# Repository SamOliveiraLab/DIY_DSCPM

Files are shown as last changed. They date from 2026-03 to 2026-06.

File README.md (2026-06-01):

# An Open-Source Platform Enabling Continuous, Low-Flow Control for Long-Term Operation in Biotechnology Systems

A GUI software and hardware platform for imposing flow rates and behaviors in a DIY pump mechanism. Supports multiple pump connections, four flow behavior modes, scheduled command sequences, and experiment file generation.

## Demo Videos

Hardware Demo (https://www.youtube.com/watch?v=BdsErtyMBxU)
GUI Demo (https://www.youtube.com/watch?v=6b1y6uDTwsg)

Full DSCPM Edge Detection playlist: <https://www.youtube.com/playlist?list=PL5P5w8v6POUNH2w5X_0y1NKzEqolb6u0d>

---

## Table of Contents

1. [Requirements](#requirements)
2. [Project Structure](#project-structure)
3. [Setup](#setup)
4. [Running the Application](#running-the-application)
5. [GUI Overview](#gui-overview)
6. [Connecting Pumps](#connecting-pumps)
7. [Pump Controls](#pump-controls)
8. [Flow Behaviors](#flow-behaviors)
9. [Pause / Resume / Restart](#pause--resume--restart)
10. [Text File Scheduling](#text-file-scheduling)
11. [Create Experiment Dialog](#create-experiment-dialog)
12. [Text File Format](#text-file-format)
13. [Arduino Command Protocol](#arduino-command-protocol)
14. [Troubleshooting](#troubleshooting)

---

## Requirements

- Python 3.8+
- PyQt5
- pyserial
- Arduino board with the DSCPM firmware loaded 

Install Python dependencies (pick one):

**uv (recommended):**

```bash
uv sync
```

**pip:**

```bash
pip install PyQt5 pyserial
```

## Project Structure

```
DSCPM_v2/
├── Arduino_code/
│   └── pump_JS_07222025.ino    # Arduino firmware for pump control
├── Python code/
│   ├── GUI.py                  # Entry point - launches the application
│   ├── pump_app.py             # Main window, all GUI logic and widgets
│   ├── arduino_cmds.py         # Serial communication wrapper
│   ├── autoport.py             # USB port auto-detection and connection
│   └── pump_render.png         # Pump image displayed in the GUI
└── README.md
```

## Setup

1. **Flash the Arduino**: Open `Arduino_code` in the Arduino IDE and upload it to your board. The firmware uses pins 9 and 11 for servos and pins 5, 6, 10 for solenoid valves. Baud rate is 9600.

2. **Connect hardware**: Plug the Arduino into your computer via USB. Note the serial number or device path if you plan to use manual connection.

3. **Install dependencies**: Run `uv sync` (or `pip install PyQt5 pyserial`).

## Running the Application

**With uv (from repo root):**

```bash
uv run python run_gui.py
```

**Classic (from `Python code`):**

```bash
cd "Python code"
python GUI.py
```

The Pump GUI window will open.

---

## GUI Overview

The interface is organized into rows from top to bottom:

| Row | Section | Purpose |
|-----|---|---|
| 0 | Pump Image | Visual reference of the pump hardware |
| 1 | Multi Pump Connect | Connect multiple pumps by entering serial numbers |
| 2 | Connect / Serial | Auto-connect or manually enter a serial number / device path |
| 3 | Flowrate Quick Adjust | Type a number (0–40) to change flow rate on the fly |
| 4 | On/Off + Direction | Turn the pump on/off and toggle flow direction |
| 5 | Flow Behavior | Select a flow mode, enter parameters, and apply |
| 6 | Pause / Resume / Restart | Control scheduled command execution |
| 7 | File Buttons | Create experiment, upload/change/run/exit text files |
| 8 | File Labels | Shows the currently selected file name |
| 9 | File Contents Display | Human-readable preview of the loaded command file |

---

## Connecting Pumps

### Auto Connect

Click **Auto Connect**. The software scans USB ports and connects to the first likely Arduino device. The button turns green on success.

### Manual Connect

Type a USB serial number (e.g. `054433A493735191B7D8`) or a device path (e.g. `/dev/cu.usbmodem1101`) into the serial input field and press Enter.

### Multiple Pumps

1. Enter the number of pumps (1–10) in the "Connect multiple pumps" field and press Enter.
2. A popup window appears - enter the serial number for each pump.
3. Click **Collect Serial #s**. The software connects to each Arduino and adds them to the pump dropdown.
4. Use the dropdown to switch between connected pumps.

---

## Pump Controls

### On/Off

- Click **Pump: OFF** to turn the pump on. Sends `123` to the Arduino.
- Click **Pump: ON** to turn it off. Sends `0` to the Arduino.
- The button changes color: green = on, red = off.

### Direction

- Click the **Direction** button to toggle between forward (`-->`) and backward (`<--`). Sends `321` to the Arduino.
- Direction only toggles when the pump is on.

### Quick Flowrate Adjust

Type an integer in the flowrate field and press Enter. This sends the number directly to the Arduino, which recalculates the servo delay for that flow rate in uL/min.

---

## Flow Behaviors

The **Flow Behavior** section provides four modes. Select a mode from the dropdown, fill in the visible parameters, then click **Apply Flow** to send the command.

### Constant

Steady flow in one direction.

| Parameter | Description |
|---|---|
| Flow Rate (uL/min) |  |

Command sent: `FLOWA,{rate}`

### Pulse

Intermittent on/off bursts.

| Parameter | Description |
|---|---|
| Flow Rate (uL/min) |  |
| Duty Cycle (0–1) | Fraction of each cycle the pump is active |
| Pulse Freq (Hz) | How many cycles per second |

Command sent: `FLOWB,{rate},{duty},{freq}`

### Oscillation

Back-and-forth flow.

| Parameter | Description |
|---|---|
| Flow Rate (uL/min) |  |
| Osc Freq (Hz) | Oscillation frequency |
| Osc Amplitude | Amplitude of the oscillation |

Command sent: `FLOWC,{rate},{freq},{amplitude}`

### Pulse of Oscillation

Pulsed bursts of oscillatory flow - combines both behaviors.

| Parameter | Description |
|---|---|
| Flow Rate (uL/min) |  |
| Pulse Freq (Hz) | Frequency of the pulse envelope |
| Duty Cycle (0–1) | Fraction of each pulse cycle that is active |
| Osc Amplitude | Amplitude of the oscillation within each pulse |
| Osc Freq (Hz) | Frequency of the oscillation within each pulse |

Command sent: `FLOWD,{rate},{pulse_freq},{duty},{osc_amplitude},{osc_freq}`

> **Note**: The Arduino firmware must be updated to parse and execute these `FLOW` commands. The current firmware only handles constant flow via numeric flow rate values.

---

## Pause / Resume / Restart

These buttons control scheduled command execution (from text files or generated experiments):

| Button | Action |
|---|---|
| **Pause** | Sends `0` to stop the pump. Freezes the command scheduler. All remaining command times are shifted forward so relative timing is preserved on resume. |
| **Resume** | Sends `123` to restart the pump. Unfreezes the scheduler and continues from where it left off. |
| **Restart Cycle** | Stops the current execution entirely, recalculates all command times from the original delays, and starts the full sequence over from the beginning. |

---

## Text File Scheduling

You can run pre-written command sequences from `.txt` files.

### Upload a File

Click **Upload .txt file**, browse to your file, and select it. The file name appears in the label and its contents are displayed in the preview area.

### Run a File

Click **Run .txt file**. The software parses the file, matches serial numbers to connected boards, and begins executing commands on a background thread at the scheduled times.

- If a worker is already running, new commands are merged into the existing schedule.
- If a serial number in the file doesn't match any connected board but only one board is connected, it falls back to that board.

### Change File

Click **Change current file** to cycle through previously uploaded files.

### Exit / Stop

Click **Exit current file** to kill the running scheduler, stop the pump, and clear all scheduled commands.

---

## Create Experiment Dialog

Click the purple **Create Experiment** button to open a dialog for building command sequences visually.

### Steps

1. **Select a pump** from the dropdown (uses connected pump names).
2. **Enter the time** in seconds from the start of the experiment.
3. **Choose a behavior**: Turn On, Turn Off, Change Direction, Constant, Pulse, Oscillation, or Pulse of Oscillation.
4. **Fill in the parameters** that appear for the selected behavior.
5. Click **Add Step**. The step appears in the table below.
6. Repeat for all steps in your experiment.

### Managing Steps

- Select a row in the table and click **Remove Selected** to delete it.
- Steps are sorted by time when the file is generated.

### Generating the File

Click **Generate & Save File**. A save dialog appears - choose a location and filename. The software:

1. Writes the `.txt` file to disk in the standard command format.
2. Loads it as the current file in the main GUI.
3. Displays the parsed commands in the file contents preview.

You can then click **Run .txt file** to execute the experiment immediately.

---

## Text File Format

Command files use this format, with entries separated by `%%%%%%%%%`:

```
SERIAL*********COMMAND#########DELAY%%%%%%%%%SERIAL*********COMMAND#########DELAY
```

| Field | Description |
|---|---|
| `SERIAL` | The Arduino's USB serial number (e.g. `054433A493735191B7D8`) |
| `COMMAND` | Any valid command string (see table below) |
| `DELAY` | Time in seconds from the start of execution |

### Example File

```
054433A493735191B7D8*********123#########0%%%%%%%%%054433A493735191B7D8*********FLOWA,10.0#########2%%%%%%%%%054433A493735191B7D8*********FLOWB,15.0,0.5,2.0#########30%%%%%%%%%054433A493735191B7D8*********0#########60
```

This sequence:
1. At 0s - Turn pump on
2. At 2s - Constant flow at 10 uL/min
3. At 30s - Switch to pulse mode (15 uL/min, 50% duty, 2 Hz)
4. At 60s - Turn pump off

---

## Arduino Command Protocol

Communication runs at **9600 baud**. The Arduino sends `READY` on startup; Python waits for this before proceeding.

### Commands (Python to Arduino)

| Command | Action |
|---|---|
| `0` | Turn pump off. Saves position to EEPROM. |
| `123` | Turn pump on. |
| `321` | Toggle flow direction. |
| `456` | Request status log (position, direction, valve state). |
| Any float (e.g. `10.5`) | Set flow rate in uL/min. Recalculates servo delay. |
| `FLOWA,{rate}` | Constant flow mode (firmware update required). |
| `FLOWB,{rate},{duty},{freq}` | Pulse mode (firmware update required). |
| `FLOWC,{rate},{freq},{amp}` | Oscillation mode (firmware update required). |
| `FLOWD,{rate},{pfreq},{duty},{oamp},{ofreq}` | Pulse of oscillation mode (firmware update required). |

### Responses (Arduino to Python)

| Response | When |
|---|---|
| `READY` | On startup, signals handshake complete |
| `System OFF. Position saved.` | After command `0` |
| `Pumps ON` | After command `123` |
| `Direction switched.` | After command `321` |
| `LOG: Position: X, FWD: Y...` | After command `456` |
| `Flow rate changed to X uL/min` | After a numeric flow rate command |

---

## Troubleshooting

**App won't start / ModuleNotFoundError**
- Make sure you've installed dependencies: `pip install PyQt5 pyserial`
- Run from inside the `Python code/` directory so relative imports work.

**"No device found" on connect**
- Check that the Arduino is plugged in via USB.
- On macOS, verify the device appears under `/dev/cu.*` (run `ls /dev/cu.*` in terminal).
- Try entering the device path manually (e.g. `/dev/cu.usbmodem1101`).

**Connect button turns red**
- The auto-detection couldn't find a matching device. Try manual serial entry or check USB connection.

**Pump doesn't respond to FLOW commands**
- The Arduino firmware (`pump_JS_07222025.ino`) does not yet handle `FLOWA`/`FLOWB`/`FLOWC`/`FLOWD` commands. Numeric flow rate changes and on/off/direction work. The firmware needs to be updated to parse the new comma-separated flow commands.

**Pause/Resume not working**
- These buttons only work when a text file schedule is running. For manual control, use the On/Off button directly.

**File displays "no valid commands found"**
- Check that the file uses the correct format: `SERIAL*********COMMAND#########DELAY` with `%%%%%%%%%` separators.

**Multiple pumps - wrong pump receives commands**
- Use the pump dropdown to select which pump you're controlling manually.
- In text files, make sure each command line uses the correct serial number for the target pump.

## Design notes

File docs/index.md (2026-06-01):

---
layout: default
---

This platform provides open-source software and hardware for imposing programmable flow rates and behaviors using a DIY syringe pump. It includes a desktop GUI for real-time pump control, Arduino firmware for motor and valve actuation, and four configurable flow modes - Constant, Pulse, Oscillation, and Pulse of Oscillation. Users can build and run scheduled experiments from the GUI and export them as text-based command files.

<p align="center">
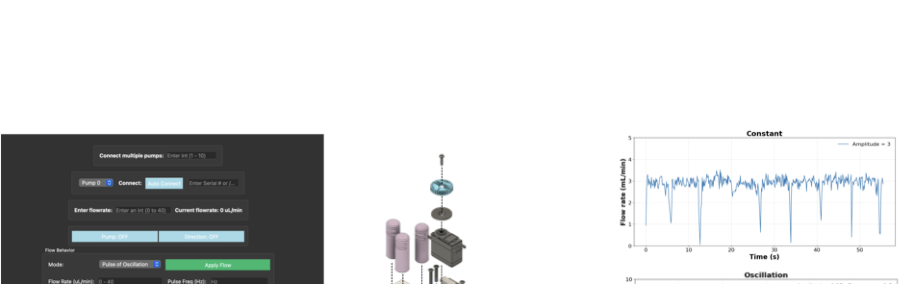
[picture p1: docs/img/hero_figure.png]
Platform Overview - GUI, Pump Hardware, Flow Behaviors
  
</p>

[View on GitHub](https://github.com/SamOliveiraLab/DIY_DSCPM){: .btn }

---

## Demos

<table align="center">
  <tr>
    <td align="center">
      <iframe width="420" height="236" src="https://www.youtube.com/embed/BdsErtyMBxU" frameborder="0" allowfullscreen></iframe>
      <br><b>Hardware Demo</b>
    </td>
    <td align="center">
      <iframe width="420" height="236" src="https://www.youtube.com/embed/6b1y6uDTwsg" frameborder="0" allowfullscreen></iframe>
      <br><b>GUI Demo</b>
    </td>
    <td align="center">
      <iframe width="420" height="236" src="https://www.youtube.com/embed/videoseries?list=PL5P5w8v6POUNH2w5X_0y1NKzEqolb6u0d" frameborder="0" allowfullscreen></iframe>
      <br><b><a href="https://www.youtube.com/playlist?list=PL5P5w8v6POUNH2w5X_0y1NKzEqolb6u0d" style="color: inherit; text-decoration: none;">Edge Detection Playlist</a></b>
    </td>
  </tr>
</table>

---

## Quick Links

| Page | Description |
|---|---|
| [Setup & Installation](setup.html) | Requirements, dependencies, and how to run |
| [GUI User Guide](guide.html) | Full walkthrough of every feature |
| [Flow Behaviors](flow.html) | Constant, Pulse, Oscillation, and Pulse of Oscillation modes |
| [Experiment Builder](experiment.html) | Creating and running scheduled experiments |
| [Arduino Protocol](protocol.html) | Command format between Python and the microcontroller |
| [Troubleshooting](troubleshooting.html) | Common issues and fixes |

---

## Project Structure

```
DIY_DSCPM/
├── Arduino_code/
│   └── pump_JS_07222025.ino    # Arduino firmware
├── Python code/
│   ├── GUI.py                  # Entry point
│   ├── pump_app.py             # Main window and logic
│   ├── arduino_cmds.py         # Serial communication
│   ├── autoport.py             # USB auto-detection
│   └── pump_render.png         # Pump image
├── dist/
│   ├── PumpGUI.app             # Standalone macOS app
│   └── PumpGUI                 # Standalone CLI executable
└── README.md
```

---

*Developed at the [Oliveira Lab](https://github.com/SamOliveiraLab), North Carolina A&T State University.*

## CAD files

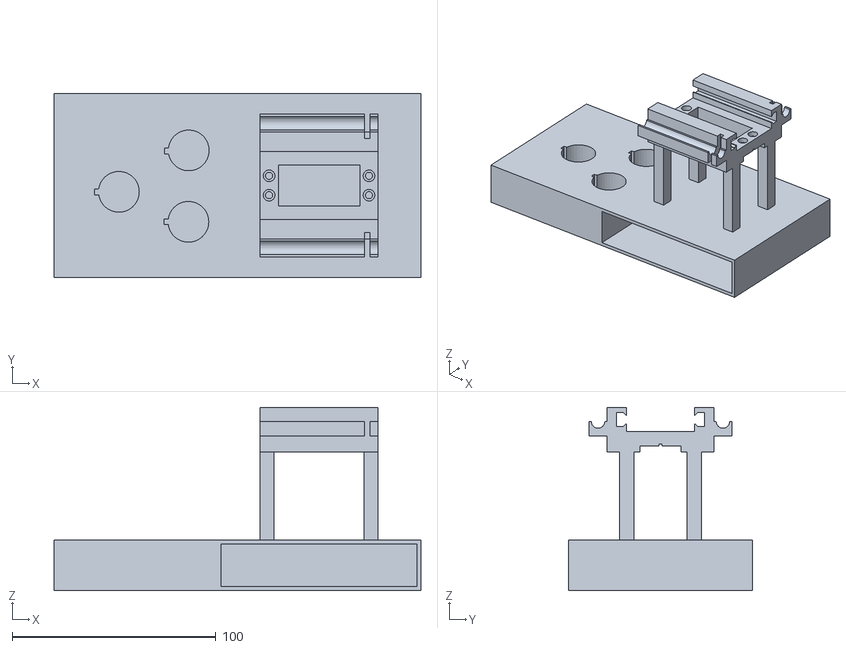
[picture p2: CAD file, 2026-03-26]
Design Files/DIY PUMP – MainBase.stl
180.0 x 90.2 x 90.0

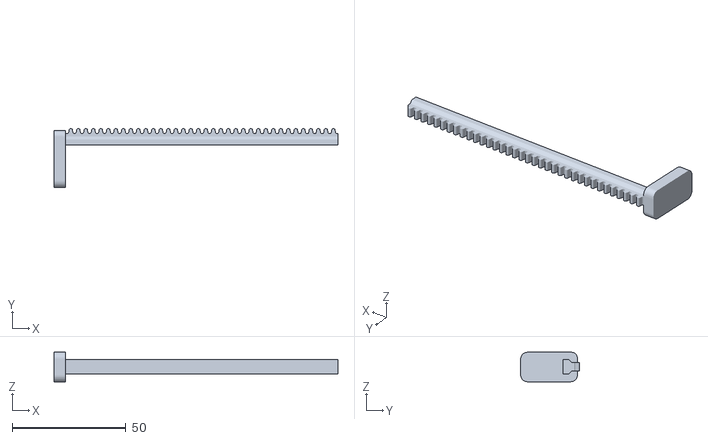
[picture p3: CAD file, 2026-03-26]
Design Files/Pusher_125mm_Long.stl
125.0 x 25.8 x 13.0

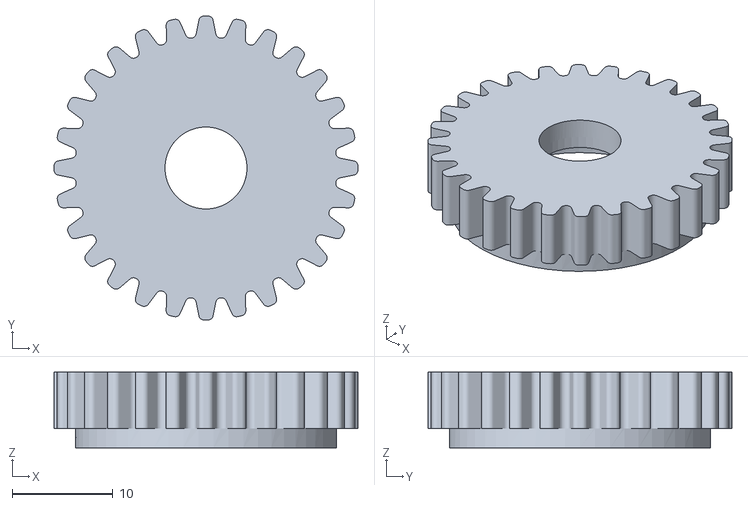
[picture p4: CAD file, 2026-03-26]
Design Files/Pinion_Gear_with_Hole.stl
30.2 x 30.2 x 7.51

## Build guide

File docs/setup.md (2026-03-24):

---
layout: default
title: Setup & Installation
---

# Setup & Installation

[Back to Home](./)

---

## Requirements

- Python 3.8+
- PyQt5
- pyserial
- Arduino board with the pump firmware loaded

## Install Dependencies

```bash
pip install PyQt5 pyserial
```

## Flash the Arduino

1. Open `Arduino_code/pump_JS_07222025.ino` in the Arduino IDE.
2. Upload it to your board.
3. The firmware uses:
   - **Pins 9, 11** for servo motors
   - **Pins 5, 6, 10** for solenoid valves
   - **Baud rate:** 9600

## Run from Source

```bash
cd "Python code"
python GUI.py
```

## Run the Packaged App (macOS)

If you have the pre-built app:

- **Double-click** `dist/PumpGUI.app`, or
- **From terminal:** `./dist/PumpGUI`

No Python installation required for the packaged version.

---

[Back to Home](./)

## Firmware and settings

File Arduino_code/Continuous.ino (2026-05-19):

#include <Servo.h>
#include <EEPROM.h>

// =========================
// Hardware Setup
// =========================
Servo myservo;
Servo servo;   // spare / unused, kept for compatibility

const int SERVO_PIN = 9;
const int SPARE_SERVO_PIN = 11;

int s1valve = 5;
int s2valve = 6;
int s3valve = 10;

// =========================
// Continuous Servo Settings
// =========================
const int SERVO_NEUTRAL_US = 1492;   // calibrated neutral PWM

// =========================
// Syringe Parameters
// IMPORTANT: keep innerdiameter
// =========================
float innerdiameter = 1.03;   // mm
float innerradius   = 1;
float syringeArea   = 1;   // mm^2


// =========================
// Plunger Travel Parameters
// =========================
float plungerTravelPerDirectionMM = 52.1;

// =========================
// Flow Mode State
// =========================
int flowMode = 0;   // 0 = constant, 1 = pulse, 2 = oscillation, 3 = pulse+oscillation

float pulseRate = 85.0;   // uL/min
float pulseDuty = 0.5;    // fraction, 0 to 1
float pulseFreq = 0.5;    // Hz

unsigned long pulseCycleStartTime = 0;
bool pulseIsOn = true;

// accumulated actual moving time within current direction
unsigned long accumulatedMoveTimeMs = 0;
unsigned long lastMoveUpdateTime = 0;

// =========================
// Oscillation State
// =========================
float oscRate = 110.0;          // mean flowrate, uL/min
float oscFreq = 0.5;            // Hz
float oscAmp  = 10.0;           // amplitude, uL/min

unsigned long oscStartTime = 0;
unsigned long lastOscUpdateMs = 0;

float oscInstantRate = 110.0;
float oscInstantOffset = 57.0;

// =========================
// Pulse + Oscillation State
// =========================
float pulseOscRate  = 110.0;   // mean flowrate, uL/min
float pulseOscPFreq = 0.5;     // pulse frequency, Hz
float pulseOscDuty  = 0.5;     // pulse duty fraction
float pulseOscAmp   = 10.0;    // oscillation amplitude, uL/min
float pulseOscOFreq = 0.5;     // oscillation frequency, Hz

unsigned long pulseOscStartTime = 0;
unsigned long lastPulseOscUpdateMs = 0;

float pulseOscInstantRate = 110.0;
float pulseOscInstantOffset = 57.0;

// =========================
// State Variables
// =========================

int infuse = 1;
int fwd = 0;             // 0 = forward, 1 = reverse
int on = 1;              // 1 = running, 0 = paused/off
int paused = 0;

int valvestate = 1;
int ODremainder = 100;
int pos = 0;

float flowrate = 85.0;         // uL/min
float currentVelocity = 0.0;   // mm/min
float currentOffset = 57;        // PWM offset relative to neutral

unsigned long currentDirectionDurationMs = 5000;
unsigned long lastSwitchTime = 0;
unsigned long pauseStartTime = 0;

// =========================
// EEPROM addresses
// =========================
const int EEPROM_ADDR_ON        = 0;
const int EEPROM_ADDR_FWD       = 1;
const int EEPROM_ADDR_INFUSE    = 2;
const int EEPROM_ADDR_VALVE     = 3;
const int EEPROM_ADDR_FLOW_X100 = 10;

// =========================
// Calibration Data (REAL VALUES)
// flowrate -> PWM offset
// =========================

const int N_CAL = 7;

// These MUST be your real measured flowrates (uL/min)
const float FLOWRATE_POINTS[N_CAL] = {
  85.0,
  97.3,
  112.8,
  128.6,
  149.2,
  173.9,
  205.4
};

// Keep your offsets exactly as calibrated
const int OFFSET_POINTS[N_CAL] = {
  57, 62, 67, 72, 77, 82, 87
};

// =========================
// Save / Load State
// =========================
void saveStateToEEPROM() {
  EEPROM.update(EEPROM_ADDR_ON, on);
  EEPROM.update(EEPROM_ADDR_FWD, fwd);
  EEPROM.update(EEPROM_ADDR_INFUSE, infuse);
  EEPROM.update(EEPROM_ADDR_VALVE, valvestate);

  int flow_x100 = (int)(flowrate * 100.0);
  EEPROM.put(EEPROM_ADDR_FLOW_X100, flow_x100);

  Serial.println(F("[EEPROM] State saved."));
}

void loadStateFromEEPROM() {
  on         = EEPROM.read(EEPROM_ADDR_ON);
  fwd        = EEPROM.read(EEPROM_ADDR_FWD);
  infuse     = EEPROM.read(EEPROM_ADDR_INFUSE);
  valvestate = EEPROM.read(EEPROM_ADDR_VALVE);

  int flow_x100 = 0;
  EEPROM.get(EEPROM_ADDR_FLOW_X100, flow_x100);
  flowrate = flow_x100 / 100.0;

  if (on != 0 && on != 1) on = 1;
  if (fwd != 0 && fwd != 1) fwd = 0;
  if (infuse != 0 && infuse != 1) infuse = 1;
  if (valvestate != 0 && valvestate != 1) valvestate = 1;
  if (flowrate <= 0.0 || flowrate > 10000.0) flowrate = 85.0;
}

float computeOscillationRate() {
  float t = (millis() - oscStartTime) / 1000.0;   // seconds
  float q = oscRate + oscAmp * sin(2.0 * 3.1415926536 * oscFreq * t);
  return q;
}
float computePulseOscillationRate() {
  float t = (millis() - pulseOscStartTime) / 1000.0;   // seconds
  float q = pulseOscRate + pulseOscAmp * sin(2.0 * 3.1415926536 * pulseOscOFreq * t);
  return q;
}

void updateOscillationOutput() {
  unsigned long now = millis();

  // update only every 100 ms
  if (now - lastOscUpdateMs < 100) {
    int pulse = (int)(SERVO_NEUTRAL_US + ((fwd == 0) ? oscInstantOffset : -oscInstantOffset));
    myservo.writeMicroseconds(pulse);
    return;
  }

  lastOscUpdateMs = now;

  float q = computeOscillationRate();

  // do not allow negative or zero rate
  if (q < FLOWRATE_POINTS[0]) q = FLOWRATE_POINTS[0];
  if (q > FLOWRATE_POINTS[N_CAL - 1]) q = FLOWRATE_POINTS[N_CAL - 1];

  float offsetCandidate = flowrateToOffset(q);
  if (offsetCandidate < 0.0) {
    myservo.writeMicroseconds(SERVO_NEUTRAL_US);
    return;
  }

  oscInstantRate = q;
  oscInstantOffset = offsetCandidate;

  int pulse = (int)(SERVO_NEUTRAL_US + ((fwd == 0) ? oscInstantOffset : -oscInstantOffset));
  myservo.writeMicroseconds(pulse);

  Serial.print(F("[OSC] Rate: "));
  Serial.print(oscInstantRate, 4);
  Serial.print(F(" uL/min, Offset: "));
  Serial.println(oscInstantOffset, 4);
}
void updatePulseOscillationOutput() {
  bool newPulseState = computePulseState();

  if (newPulseState != pulseIsOn) {
    pulseIsOn = newPulseState;
    Serial.print(F("[FLOWD] Pulse state changed: "));
    Serial.println(pulseIsOn ? F("ON") : F("OFF"));
  }

  if (!pulseIsOn) {
    myservo.writeMicroseconds(SERVO_NEUTRAL_US);
    return;
  }

  unsigned long now = millis();

  // update oscillation only every 100 ms
  if (now - lastPulseOscUpdateMs < 100) {
    int pulse = (int)(SERVO_NEUTRAL_US + ((fwd == 0) ? pulseOscInstantOffset : -pulseOscInstantOffset));
    myservo.writeMicroseconds(pulse);
    return;
  }

  lastPulseOscUpdateMs = now;

  float q = computePulseOscillationRate();

  if (q < FLOWRATE_POINTS[0]) q = FLOWRATE_POINTS[0];
  if (q > FLOWRATE_POINTS[N_CAL - 1]) q = FLOWRATE_POINTS[N_CAL - 1];

  float offsetCandidate = flowrateToOffset(q);
  if (offsetCandidate < 0.0) {
    myservo.writeMicroseconds(SERVO_NEUTRAL_US);
    return;
  }

  pulseOscInstantRate = q;
  pulseOscInstantOffset = offsetCandidate;

  int pulse = (int)(SERVO_NEUTRAL_US + ((fwd == 0) ? pulseOscInstantOffset : -pulseOscInstantOffset));
  myservo.writeMicroseconds(pulse);

  Serial.print(F("[FLOWD] Inst rate: "));
  Serial.print(pulseOscInstantRate, 4);
  Serial.print(F(" uL/min, Offset: "));
  Serial.println(pulseOscInstantOffset, 4);
}
// =========================
// Physics
// =========================
float flowToVelocity(float Q_uL_per_min) {
  return Q_uL_per_min / syringeArea;
}

unsigned long computeDirectionDurationMs(float travelMM, float velocityMMperMin) {
  if (velocityMMperMin <= 0.0) return 0;

  float durationMin = travelMM / velocityMMperMin;
  float durationMsFloat = durationMin * 60000.0;

  if (durationMsFloat < 1.0) durationMsFloat = 1.0;
  return (unsigned long)(durationMsFloat + 0.5);
}
  bool computePulseState() {
  if (pulseFreq <= 0.0) return false;

  float periodMs = 1000.0 / pulseFreq;
  float onTimeMs = periodMs * pulseDuty;

  if (periodMs <= 0.0) return false;

  unsigned long elapsed = millis() - pulseCycleStartTime;
  float phaseMs = fmod((float)elapsed, periodMs);

  return (phaseMs < onTimeMs);
}

void updateConstantOutput() {
  int pulse = (int)(SERVO_NEUTRAL_US + ((fwd == 0) ? currentOffset : -currentOffset));
  myservo.writeMicroseconds(pulse);
}

void updatePulseOutput() {
  bool newPulseState = computePulseState();

  if (newPulseState != pulseIsOn) {
    pulseIsOn = newPulseState;
    Serial.print(F("[PULSE] State changed: "));
    Serial.println(pulseIsOn ? F("ON") : F("OFF"));
  }

  if (pulseIsOn) {
    int pulse = (int)(SERVO_NEUTRAL_US + ((fwd == 0) ? currentOffset : -currentOffset));
    myservo.writeMicroseconds(pulse);
  } else {
    myservo.writeMicroseconds(SERVO_NEUTRAL_US);
  }
}

void updateMotorOutput() {
  if (on == 0 || paused == 1) {
    myservo.writeMicroseconds(SERVO_NEUTRAL_US);
    return;
  }

  if (flowMode == 0) {
    updateConstantOutput();
  } else if (flowMode == 1) {
    updatePulseOutput();
  } else if (flowMode == 2) {
    updateOscillationOutput();
  } else if (flowMode == 3) {
    updatePulseOscillationOutput();
  } else {
    myservo.writeMicroseconds(SERVO_NEUTRAL_US);
  }
}

void updateAccumulatedMoveTime() {
  unsigned long now = millis();

  if (lastMoveUpdateTime == 0) {
    lastMoveUpdateTime = now;
    return;
  }

  unsigned long dt = now - lastMoveUpdateTime;
  lastMoveUpdateTime = now;

  if (flowMode == 0) {
    accumulatedMoveTimeMs += dt;
  } else if (flowMode == 1) {
    if (pulseIsOn) {
      accumulatedMoveTimeMs += dt;
    }
  } else if (flowMode == 2) {
    accumulatedMoveTimeMs += dt;
  } else if (flowMode == 3) {
    if (pulseIsOn) {
      accumulatedMoveTimeMs += dt;
    }
  }
}
// =========================
// Calibration Mapping
// flowrate -> PWM offset
// =========================
float flowrateToOffset(float q) {

  if (q < FLOWRATE_POINTS[0] || q > FLOWRATE_POINTS[N_CAL - 1]) {
    Serial.print(F("ERROR: Flowrate out of calibrated range. Allowed range: "));
    Serial.print(FLOWRATE_POINTS[0], 4);
    Serial.print(F(" to "));
    Serial.print(FLOWRATE_POINTS[N_CAL - 1], 4);
    Serial.println(F(" uL/min"));
    return -1.0;
  }

  // exact match
  for (int i = 0; i < N_CAL; i++) {
    if (fabs(q - FLOWRATE_POINTS[i]) < 0.0001) {
      return OFFSET_POINTS[i];
    }
  }

  // interpolation
  for (int i = 0; i < N_CAL - 1; i++) {
    float Qi  = FLOWRATE_POINTS[i];
    float Qi1 = FLOWRATE_POINTS[i + 1];

    if (q > Qi && q < Qi1) {
      float offset_i  = OFFSET_POINTS[i];
      float offset_i1 = OFFSET_POINTS[i + 1];

      float offsetStar =
        offset_i + ((q - Qi) / (Qi1 - Qi)) * (offset_i1 - offset_i);

      return offsetStar;  
    }
  }

  Serial.println(F("ERROR: Interpolation failed."));
  return -1.0;
}

void recalculateMotionTiming() {
  currentVelocity = flowToVelocity(flowrate);     // for switch timing
  currentOffset = flowrateToOffset(flowrate);     // calibration mapping

  if (currentOffset < 0.0) {
    currentDirectionDurationMs = 0;
    return;
  }

  currentDirectionDurationMs =
    computeDirectionDurationMs(plungerTravelPerDirectionMM, currentVelocity);
}

void applyFlowRate(float newFlowrate) {
  flowrate = newFlowrate;
  recalculateMotionTiming();

  if (currentOffset < 0.0) {
    Serial.println(F("[FLOW] Command rejected."));
    return;
  }

  flowMode = 0;

  accumulatedMoveTimeMs = 0;
  lastMoveUpdateTime = millis();
  lastSwitchTime = millis();

  Serial.println(F("[FLOW] Constant flow applied."));
  Serial.print(F("[FLOW] Requested flow rate: "));
  Serial.println(flowrate, 4);

  Serial.print(F("[FLOW] PWM offset: "));
  Serial.println(currentOffset, 4);

  Serial.print(F("[FLOW] Direction duration: "));
  Serial.println(currentDirectionDurationMs);

  saveStateToEEPROM();
}
// =========================
// Valve / Servo Updates
// =========================
void updateValves() {
  analogWrite(s1valve, valvestate == 0 ? 255 : 0);
  analogWrite(s2valve, valvestate == 1 ? 255 : 0);
  analogWrite(s3valve, 0);
}

void driveServo() {
  updateMotorOutput();
}

void stopOutputs() {
  myservo.writeMicroseconds(SERVO_NEUTRAL_US);
  analogWrite(s1valve, 0);
  analogWrite(s2valve, 0);
  analogWrite(s3valve, 0);
}

// =========================
// Debug Log
// =========================
void printDebugLog() {
  Serial.println(F("----- DEBUG LOG -----"));
  Serial.print(F("FWD: "));
  Serial.println(fwd);

  Serial.print(F("Infuse: "));
  Serial.println(infuse);

  Serial.print(F("ValveState (raw): "));
  Serial.println(valvestate);

  Serial.print(F("Flow mode: "));
  if (flowMode == 0) Serial.println(F("CONSTANT"));
  else if (flowMode == 1) Serial.println(F("PULSE"));
  else if (flowMode == 2) Serial.println(F("OSCILLATION"));
  else if (flowMode == 3) Serial.println(F("PULSE+OSCILLATION"));
  else Serial.println(F("UNKNOWN"));

  Serial.print(F("Flowrate: "));
  Serial.print(flowrate, 4);
  Serial.println(F(" uL/min"));

  Serial.print(F("innerdiameter: "));
  Serial.print(innerdiameter, 4);
  Serial.println(F(" mm"));

  Serial.print(F("Syringe area: "));
  Serial.print(syringeArea, 6);
  Serial.println(F(" mm^2"));

  Serial.print(F("Plunger velocity: "));
  Serial.print(currentVelocity, 6);
  Serial.println(F(" mm/min"));

  Serial.print(F("PWM offset: "));
  Serial.println(currentOffset, 4);

  Serial.print(F("Plunger travel per direction: "));
  Serial.print(plungerTravelPerDirectionMM, 4);
  Serial.println(F(" mm"));

  Serial.print(F("Direction duration: "));
  Serial.print(currentDirectionDurationMs);
  Serial.println(F(" ms"));

  Serial.print(F("Accumulated move time: "));
  Serial.print(accumulatedMoveTimeMs);
  Serial.println(F(" ms"));

  Serial.print(F("Pump ON: "));
  Serial.println(on);

  Serial.print(F("Paused: "));
  Serial.println(paused);

  if (flowMode == 1) {
    Serial.print(F("Pulse rate: "));
    Serial.print(pulseRate, 4);
    Serial.println(F(" uL/min"));

    Serial.print(F("Pulse duty fraction: "));
    Serial.println(pulseDuty, 4);

    Serial.print(F("Pulse frequency: "));
    Serial.print(pulseFreq, 4);
    Serial.println(F(" Hz"));

    Serial.print(F("Pulse state: "));
    Serial.println(pulseIsOn ? "ON" : "OFF");
  }
  if (flowMode == 2) {
  Serial.print(F("Osc mean rate: "));
  Serial.print(oscRate, 4);
  Serial.println(F(" uL/min"));

  Serial.print(F("Osc frequency: "));
  Serial.print(oscFreq, 4);
  Serial.println(F(" Hz"));

  Serial.print(F("Osc amplitude: "));
  Serial.print(oscAmp, 4);
  Serial.println(F(" uL/min"));

  Serial.print(F("Osc instantaneous rate: "));
  Serial.print(oscInstantRate, 4);
  Serial.println(F(" uL/min"));

  Serial.print(F("Osc instantaneous offset: "));
  Serial.println(oscInstantOffset, 4);
}
  if (flowMode == 3) {
    Serial.print(F("FLOWD mean rate: "));
    Serial.print(pulseOscRate, 4);
    Serial.println(F(" uL/min"));

    Serial.print(F("FLOWD pulse frequency: "));
    Serial.print(pulseOscPFreq, 4);
    Serial.println(F(" Hz"));

    Serial.print(F("FLOWD duty fraction: "));
    Serial.println(pulseOscDuty, 4);

    Serial.print(F("FLOWD oscillation amplitude: "));
    Serial.print(pulseOscAmp, 4);
    Serial.println(F(" uL/min"));

    Serial.print(F("FLOWD oscillation frequency: "));
    Serial.print(pulseOscOFreq, 4);
    Serial.println(F(" Hz"));

    Serial.print(F("FLOWD pulse state: "));
    Serial.println(pulseIsOn ? F("ON") : F("OFF"));

    Serial.print(F("FLOWD instant rate: "));
    Serial.print(pulseOscInstantRate, 4);
    Serial.println(F(" uL/min"));

    Serial.print(F("FLOWD instant offset: "));
    Serial.println(pulseOscInstantOffset, 4);
  }

  Serial.println(F("----------------------"));
}

// =========================
// Direction Toggle
// =========================
void toggleDirection() {
  fwd = 1 - fwd;
  infuse = 1 - infuse;
  valvestate = (fwd == 0) ? 1 : 0;

  Serial.println(F("[DIR] Direction toggled."));
  Serial.print(F("[DIR] FWD = "));
  Serial.println(fwd);
  Serial.print(F("[DIR] INFUSE = "));
  Serial.println(infuse);
  Serial.print(F("[DIR] ValveState = "));
  Serial.println(valvestate);

  saveStateToEEPROM();
}

void autoSwitchDirectionIfNeeded() {
  if (on == 0 || paused == 1) return;
  if (currentDirectionDurationMs == 0) return;

  if (accumulatedMoveTimeMs >= currentDirectionDurationMs) {
    toggleDirection();
    updateValves();

    accumulatedMoveTimeMs = 0;
    lastSwitchTime = millis();
    lastMoveUpdateTime = millis();

    Serial.println(F("[AUTO] End of plunger travel reached -> switched direction/valves."));
  }
}
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
void loop() {

  while (Serial.available() > 0) {

    char c = Serial.read();

    lastSerialCharTime = millis();

    if (c == '\r' || c == '\n') {
      continue;
    }

    if (cmdIndex < sizeof(cmdBuffer) - 1) {
      cmdBuffer[cmdIndex++] = c;
    }
  }

  if (cmdIndex > 0 && millis() - lastSerialCharTime > SERIAL_TIMEOUT) {

    cmdBuffer[cmdIndex] = '\0';

    Serial.print("[AUTO CMD] ");
    Serial.println(cmdBuffer);

    handleCommand(cmdBuffer);

    cmdIndex = 0;
  }

  if (on == 1 && paused == 0) {
    updateValves();
    updateMotorOutput();
    updateAccumulatedMoveTime();
    autoSwitchDirectionIfNeeded();
  } else {
    stopOutputs();
  }

  delay(10);
}

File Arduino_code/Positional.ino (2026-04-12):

#include <Servo.h>
#include <EEPROM.h>

// --- Hardware Setup ---
Servo myservo;
Servo servo;
int s1valve = 5;
int s2valve = 6;
int s3valve = 10;
int holdvoltage = 80;
int maxangle = 70;
int minangle = 5;

// --- State Variables ---
String incomingByte = "1";
int infuse = 1;
int pos = 5;
int fwd = 0;
int on = 1;
int valvestate = EEPROM.read(3);
int ODremainder = 100;
float amountpumped = 0;

// --- Syringe Parameters ---
float innerdiameter = 0.485;
float mmperdegree = 0.256;
float degper180 = 270;
float volmultiplier = degper180 / 180.0;
float innerradius = innerdiameter / 2;
float uLperdeg = 3.1415926536 * (innerradius * innerradius) * (mmperdegree * volmultiplier);

// --- Flowrate and Delay ---
float flowrate = 1.5;
float minperdeg = uLperdeg / flowrate;
float millisperdeg = minperdeg * 60000;
int newdelay = int(millisperdeg);

// --- Flow calculation ---
void calculatenewdelay(float newflowrate) {
  flowrate = newflowrate;
  uLperdeg = 3.1415926536 * (innerradius * innerradius) * (mmperdegree * volmultiplier);
  minperdeg = uLperdeg / flowrate;
  millisperdeg = minperdeg * 60000;
  newdelay = int(millisperdeg);
}

// --- Struct ---
struct posandfwd {
  int pos;
  int fwd;
};

// --- Motion Logic ---
struct posandfwd IncrementPosition(int pos, int fwd) {
  if (on == 1) {
    if (pos == minangle) {
      valvestate = (infuse == 0) ? 1 : 0;
      fwd = 0;
      pos += 1;
      ODremainder = 100;
    } else if (pos == maxangle) {
      valvestate = (infuse == 0) ? 0 : 1;
      fwd = 1;
      pos -= 1;
      ODremainder = 100;
    } else {
      pos += (fwd == 0) ? 1 : -1;
    }
  }
  return {pos, fwd};
}

// --- Valve + Timing ---
void overdriveAndDelay(bool remainder, int pos, int valvestate, int newdelay) {
  if (remainder) {
    if (ODremainder > newdelay) {
      analogWrite(s1valve, valvestate == 0 ? 255 : 0);
      analogWrite(s2valve, valvestate == 1 ? 255 : 0);
      ODremainder -= newdelay;
      delay(newdelay);
    } else if (ODremainder > 0) {
      if (valvestate == 0) {
        analogWrite(s1valve, 255);
        analogWrite(s2valve, 0);
        delay(ODremainder);
        analogWrite(s1valve, holdvoltage);
        delay(newdelay - ODremainder);
      } else {
        analogWrite(s1valve, 0);
        analogWrite(s2valve, 255);
        delay(ODremainder);
        analogWrite(s2valve, holdvoltage);
        delay(newdelay - ODremainder);
      }
      ODremainder = 0;
    } else {
      delay(newdelay);
    }
  } else {
    if (pos == minangle || pos == maxangle) {
      analogWrite(s3valve, 255);
      delay(10);

      if (valvestate == 0) {
        analogWrite(s1valve, 255);
        analogWrite(s2valve, 0);
        delay(50);
        analogWrite(s3valve, 0);
        delay(100);
        analogWrite(s1valve, holdvoltage);
      } else {
        analogWrite(s1valve, 0);
        analogWrite(s2valve, 255);
        delay(50);
        analogWrite(s3valve, 0);
        delay(100);
        analogWrite(s2valve, holdvoltage);
      }

      if (newdelay > 160) delay(newdelay - 160);
    } else {
      delay(newdelay);
    }
  }
}

// --- Debug Log ---
void printDebugLog() {
  Serial.println("----- DEBUG LOG -----");

  Serial.print("Position: ");
  Serial.println(pos);

  Serial.print("FWD: ");
  Serial.println(fwd);

  Serial.print("Infuse: ");
  Serial.println(infuse);

  Serial.print("ValveState (raw): ");
  Serial.println(valvestate);

  Serial.print("Active Valve: ");
  if (valvestate == 0) {
    Serial.println("S1 ON, S2 OFF");
  } else {
    Serial.println("S2 ON, S1 OFF");
  }

  Serial.print("ODremainder: ");
  Serial.println(ODremainder);

  Serial.print("Flowrate: ");
  Serial.print(flowrate);
  Serial.println(" uL/min");

  Serial.print("Step delay: ");
  Serial.print(newdelay);
  Serial.println(" ms");

  Serial.print("Pump ON: ");
  Serial.println(on);

  Serial.println("----------------------");
}

// --- Command Handler ---
void handleCommand(String cmd) {
  cmd.trim();

  if (cmd == "123") {
    on = 1;
    Serial.println("Pumps ON");
    return;
  }

  if (cmd == "0") {
    EEPROM.write(0, pos);
    EEPROM.write(1, fwd);
    EEPROM.write(2, infuse);
    EEPROM.write(3, valvestate);
    on = 0;
    Serial.println("System OFF. Position saved.");
    return;
  }

  if (cmd == "321") {
    fwd = 1 - fwd;
    infuse = 1 - infuse;
    Serial.println("Direction switched.");
    return;
  }

  if (cmd == "456") {
    printDebugLog();
    return;
  }

  // FLOWA command
  if (cmd.startsWith("FLOWA,")) {
    String rateString = cmd.substring(6);
    rateString.trim();
    float rate = rateString.toFloat();

    if (rate > 0) {
      calculatenewdelay(rate);
      Serial.print("Constant flow set to ");
      Serial.print(flowrate);
      Serial.println(" uL/min");
    } else {
      Serial.println("ERROR: Flow must be > 0");
    }
    return;
  }

  // Numeric flow rate
  bool isNumeric = true;
  for (unsigned int i = 0; i < cmd.length(); i++) {
    if (!isDigit(cmd[i]) && cmd[i] != '.') {
      isNumeric = false;
      break;
    }
  }

  if (isNumeric && cmd.length() > 0) {
    float rate = cmd.toFloat();

    if (rate > 0) {
      calculatenewdelay(rate);
      Serial.print("Flow rate changed to ");
      Serial.print(flowrate);
      Serial.println(" uL/min");
    } else {
      Serial.println("ERROR: Flow must be > 0");
    }
    return;
  }

  Serial.print("ERROR: Unknown command -> ");
  Serial.println(cmd);
}

// --- Main Pump Loop ---
void runPumpLogic() {
  struct posandfwd result = IncrementPosition(pos, fwd);
  pos = result.pos;
  fwd = result.fwd;

  if (on == 1) {
    amountpumped += (infuse == 0) ? uLperdeg : -uLperdeg;
  }

  myservo.write(pos);

  if (newdelay >= 100) {
    overdriveAndDelay(false, pos, valvestate, newdelay);
  } else {
    overdriveAndDelay(true, pos, valvestate, newdelay);
  }
}

// --- Setup ---
void setup() {
  pinMode(s1valve, OUTPUT);
  pinMode(s2valve, OUTPUT);
  pinMode(s3valve, OUTPUT);

  myservo.attach(9);
  servo.attach(11);

  Serial.begin(9600);
  Serial.println("READY");
}

// --- Loop ---
void loop() {
  if (Serial.available()) {
    incomingByte = Serial.readStringUntil('\n');
    handleCommand(incomingByte);
  }

  if (on == 1) {
    runPumpLogic();
  }
}

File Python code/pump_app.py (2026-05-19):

import sys
import os
from PyQt5.QtWidgets import (QApplication, QMainWindow, QLabel, QWidget, QPushButton, QLineEdit, QComboBox,
                             QVBoxLayout, QHBoxLayout, QGridLayout, QGroupBox, QMessageBox, QFileDialog,
                             QDialog, QDoubleSpinBox, QTextEdit, QTableWidget, QTableWidgetItem,
                             QHeaderView, QAbstractItemView, QScrollArea)
from PyQt5.QtGui import QFont, QPixmap
from PyQt5.QtCore import Qt, QObject, QThread, pyqtSignal
import arduino_cmds
import autoport
import threading
import time

# Josh Scheel -- joshua@e-scheel.com


class MainWindow(QMainWindow):
    def __init__(self):
        super().__init__()

        self.setWindowTitle("Pump GUI")
        self.setGeometry(700, 200, 680, 950)

        # Scrollable central area
        scroll = QScrollArea()
        scroll.setWidgetResizable(True)
        self.setCentralWidget(scroll)
        central_widget = QWidget()
        scroll.setWidget(central_widget)

        self.layout = QGridLayout()
        central_widget.setLayout(self.layout)

        # --- Pump variables ---
        self.connected = False
        self.some_connected = False
        self.current_flowrate = 0  # uL/min
        self.arduino_cmds = arduino_cmds.PumpFluidics()
        self.is_on = False
        self.fwd = False
        self.paused = False
        self._manual_state = None       # last manual running config
        self._pause_snapshot = None     # config saved when manually paused

        # --- Pump selection variables ---
        self.current_serial = ''
        self.pump_serial_dict = {'Pump 0': None}
        self.current_index = 0
        self.connected_boards = {}
        self.current_board = None

        # --- Text file variables ---
        self.fname = "No file selected"
        self.current_file_tracker = 0
        self.text_file_count = 0
        self.text_file_list = []
        self.scheduled_commands = []
        self.original_commands = []   # (delay, command, serial) for restart
        self.worker_running = False
        self.worker = None
        self.thread = None

        #####################################################################################################################
        # UI ROWS
        #####################################################################################################################

        row = 0

        # --- Row 0: Pump image ---
        pixmap_path = os.path.join(os.path.dirname(__file__), "pump_render.png")
        pixmap = QPixmap(pixmap_path)
        scaled_pixmap = pixmap.scaled(250, 250, Qt.KeepAspectRatio, Qt.SmoothTransformation)
        self.image_label = QLabel()
        self.image_label.setPixmap(scaled_pixmap)
        self.image_label.setFixedSize(scaled_pixmap.size())
        self.image_label.setStyleSheet("QLabel {border: 2px solid black;}")
        self.image_label.setAlignment(Qt.AlignTop | Qt.AlignHCenter)
        self.layout.addWidget(self.image_label, row, 0, alignment=Qt.AlignTop | Qt.AlignHCenter)
        row += 1

        # --- Row 1: Multi pump connect ---
        self.multi_button_group_box = QGroupBox()
        self.multi_button_layout = QHBoxLayout()
        self.multi_button_group_box.setMinimumSize(300, 50)
        self.multi_button_label = QLabel("Connect multiple pumps:")
        font = self.multi_button_label.font()
        font.setBold(True)
        self.multi_button_label.setFont(font)
        self.multi_button_layout.addWidget(self.multi_button_label)
        self.multi_pump_edit = QLineEdit()
        self.multi_pump_edit.setPlaceholderText('Enter int (1 - 10)')
        self.multi_pump_edit.returnPressed.connect(lambda: self.multi_pump_connect(self.multi_pump_edit.text()))
        self.multi_button_layout.addWidget(self.multi_pump_edit)
        self.multi_button_group_box.setLayout(self.multi_button_layout)
        self.layout.addWidget(self.multi_button_group_box, row, 0, alignment=Qt.AlignCenter)
        row += 1

        # --- Row 2: Connect / Serial ---
        self.connect_button_group_box = QGroupBox()
        self.connect_button_layout = QHBoxLayout()
        self.connect_button_group_box.setMinimumSize(300, 50)
        self.new_pump_dropdown = QComboBox()
        self.new_pump_dropdown.addItems(["Pump 0"])
        self.new_pump_dropdown.currentTextChanged.connect(self.new_pump_dropdown_change)
        self.connect_button_layout.addWidget(self.new_pump_dropdown)
        self.connect_button_label = QLabel("Connect:")
        font = self.connect_button_label.font()
        font.setBold(True)
        self.connect_button_label.setFont(font)
        self.connect_button_layout.addWidget(self.connect_button_label)
        self.connect_button = QPushButton('Auto Connect')
        self.connect_button.setCheckable(True)
        self.connect_button.clicked.connect(lambda: self.connect_button_clicked())
        self.connect_button.setStyleSheet('background-color: #ADD8E6; color: white; padding: 5px;')
        self.connect_button_layout.addWidget(self.connect_button)
        self.serial_edit = QLineEdit()
        self.serial_edit.setPlaceholderText('Enter Serial # or /dev/cu.*')
        self.serial_edit.returnPressed.connect(lambda: self.connect_serial(self.serial_edit.text()))
        self.connect_button_layout.addWidget(self.serial_edit)
        self.connect_button_group_box.setLayout(self.connect_button_layout)
        self.layout.addWidget(self.connect_button_group_box, row, 0, alignment=Qt.AlignCenter)
        row += 1

        # --- Row 3: Flowrate quick adjust ---
        self.flowrate_group_box = QGroupBox()
        self.flowrate_button_layout = QHBoxLayout()
        self.flowrate_group_box.setMinimumSize(450, 50)
        self.flowrate_button_label = QLabel("Enter flowrate:")
        font = self.flowrate_button_label.font()
        font.setBold(True)
        self.flowrate_button_label.setFont(font)
        self.flowrate_button_layout.addWidget(self.flowrate_button_label)
        self.flowrate_edit = QLineEdit()
        self.flowrate_edit.setPlaceholderText('Enter flow rate (uL/min)')
        self.flowrate_edit.returnPressed.connect(lambda: self.update_flowrate(self.flowrate_edit.text()))
        self.flowrate_button_layout.addWidget(self.flowrate_edit)
        self.current_flowrate_label = QLabel(f"Current flowrate: {self.current_flowrate} uL/min")
        font = self.current_flowrate_label.font()
        font.setBold(True)
        self.current_flowrate_label.setFont(font)
        self.flowrate_button_layout.addWidget(self.current_flowrate_label)
        self.flowrate_group_box.setLayout(self.flowrate_button_layout)
        self.layout.addWidget(self.flowrate_group_box, row, 0, alignment=Qt.AlignCenter)
        row += 1
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

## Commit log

2026-03-20 Initial commit for dual pump GUI
    Adds the pump GUI Python code, the companion Arduino sketch, and a brief README so the project can run end-to-end.
    Made-with: Cursor
2026-03-20 Refactor pump GUI code for improved readability and performance. Updated README with usage instructions and troubleshooting tips.
2026-03-24 Remove perfusion references, update title to DIY Dual Syringe Pump
2026-03-25 Update landing page with hero figure showing all platform components
2026-03-25 Add introductory paragraph to landing page
2026-03-26 Add design files
    [DIY PUMP – MainBase.stl, Pinion_Gear_with_Hole.stl, Pusher_125mm_Long.stl]
2026-03-26 Remove obsolete design files: MainBase.stl, Pinion_Gear_with_Hole.stl, and Pusher_125mm_Long.stl
    [DIY PUMP – MainBase.stl, Pinion_Gear_with_Hole.stl, Pusher_125mm_Long.stl]
2026-03-26 Update landing page with new demo video and adjust layout for better visibility
2026-05-19 Update .gitignore and improve flow rate handling in pump_app.py
    - Ignore macOS AppleDouble (._*) files.
    - Remove 0–40 uL/min cap; accept float flow rates with rate > 0 validation.
2026-05-19 Enhance pump_app.py with manual state management and flow command handling
    - Introduced methods to capture and restore manual pump configurations for improved pause/resume functionality.
    - Added flow command building logic based on user input for various flow modes.
    - Updated UI behavior to reflect manual state changes and ensure proper command execution.
    - Improved handling of paused state in the on/off button logic.
